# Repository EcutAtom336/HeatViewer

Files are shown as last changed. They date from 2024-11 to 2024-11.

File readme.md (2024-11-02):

# 手持热成像 - HeatViewer

## 项目简介

- 该项目是基于立创·天空星开发板-GD32F407VET6-青春版的手持热成像，使用 MLX90640 红外传感器和 OV7725 可见光图像传感器，支持红外可见光图像融合。

## 快速链接

- [Github](https://github.com/EcutAtom336/Heatviewer)

- [立创开源硬件平台](http://oshwhub.com/dter/heatviewer)

## 功能描述

- 使用 MLX90640 红外传感器，分辨率 32 \* 24，使用软件插值提高分辨率至 64 \* 48。

- 使用 OV7725 图像传感器，支持可见光融合。

- 内置 18650 锂电池，使用 Type-C 接口供充电。

- 可外接 TF 卡，截图保存至 TF 卡。

- 支持可见光照明和激光指示。

- 发射率可调。

- 中心温度和温度极值显示，高温报警。

## 用户交互

- 按键 1：电源键（屏幕面板左上）

  用于开启和关闭热成像仪。

- 按键 2：菜单键（屏幕面板右上）

  用于打开/关闭菜单。

- 按键 3：多功能键 1（屏幕面板中上）

  在菜单界面为上建，在热成像界面为可见光照明开启/关闭键。

- 按键 4：多功能键 2（屏幕面板中下）

  在菜单界面为下键，在热成像界面为激光指示开启/关闭键。

- 按键 5：多功能键 3（扳机键）

  在菜单界面为确认键，在热成像界面为截图键。

## 复刻指南

### 硬件

- 项目 BOM 表在 **/doc/production/bom** 下。

- 3D 打印外壳文件在 **/doc/production/3d_print** 下。

- PCB 制造文件在 **/doc/production/pcb** 下。

- 为减小 pcb 大小，修改天空星开发板的封装排针为贴片形式，可使用贴片排针或贴片排母加直插排针的方式，推荐使用贴片排母加直插排针的方式，以防焊接错误难以修改。

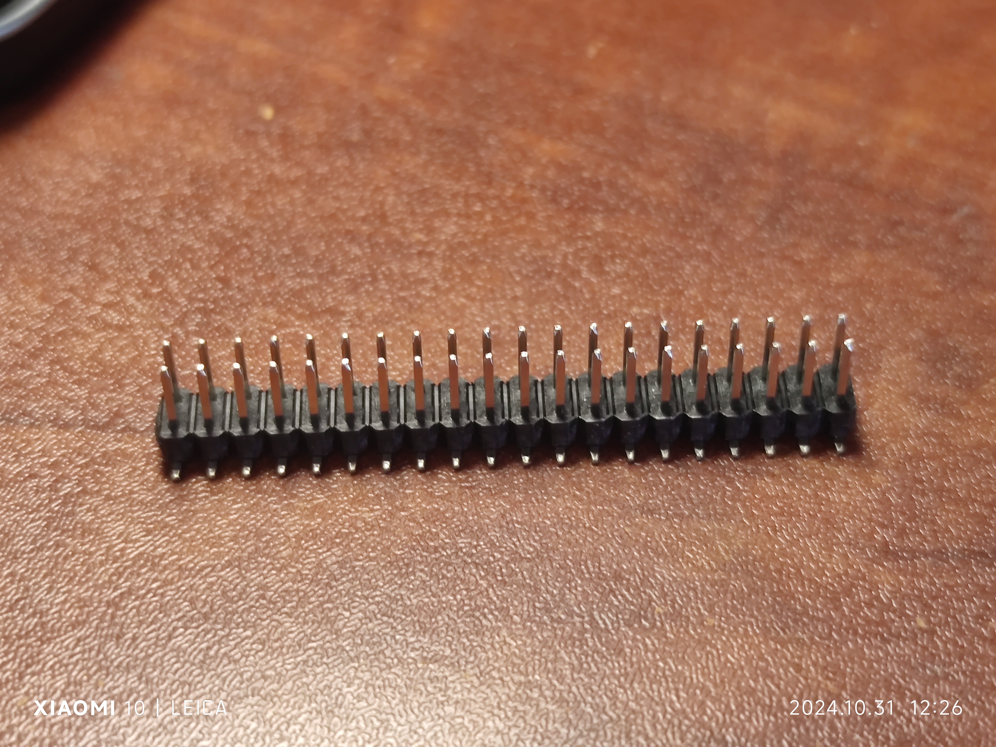
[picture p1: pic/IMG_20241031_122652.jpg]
贴片排针


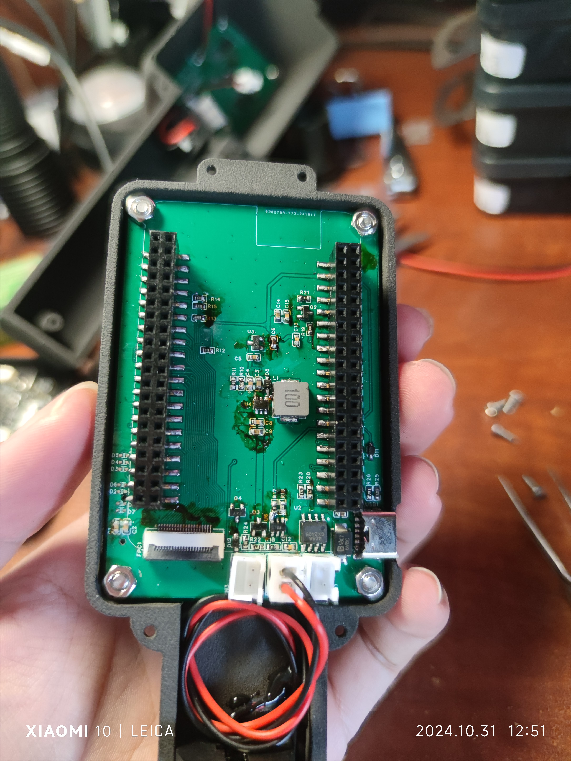
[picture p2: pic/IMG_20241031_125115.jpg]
贴片排母加直插排针


- 传感器 PCB 安装

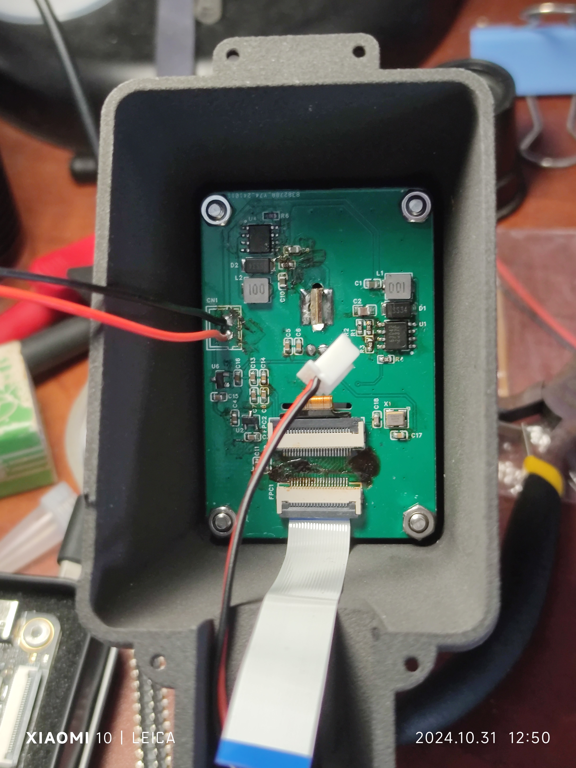
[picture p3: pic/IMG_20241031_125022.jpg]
传感器 PCB 安装


- 主控板 PCB 和电池座安装

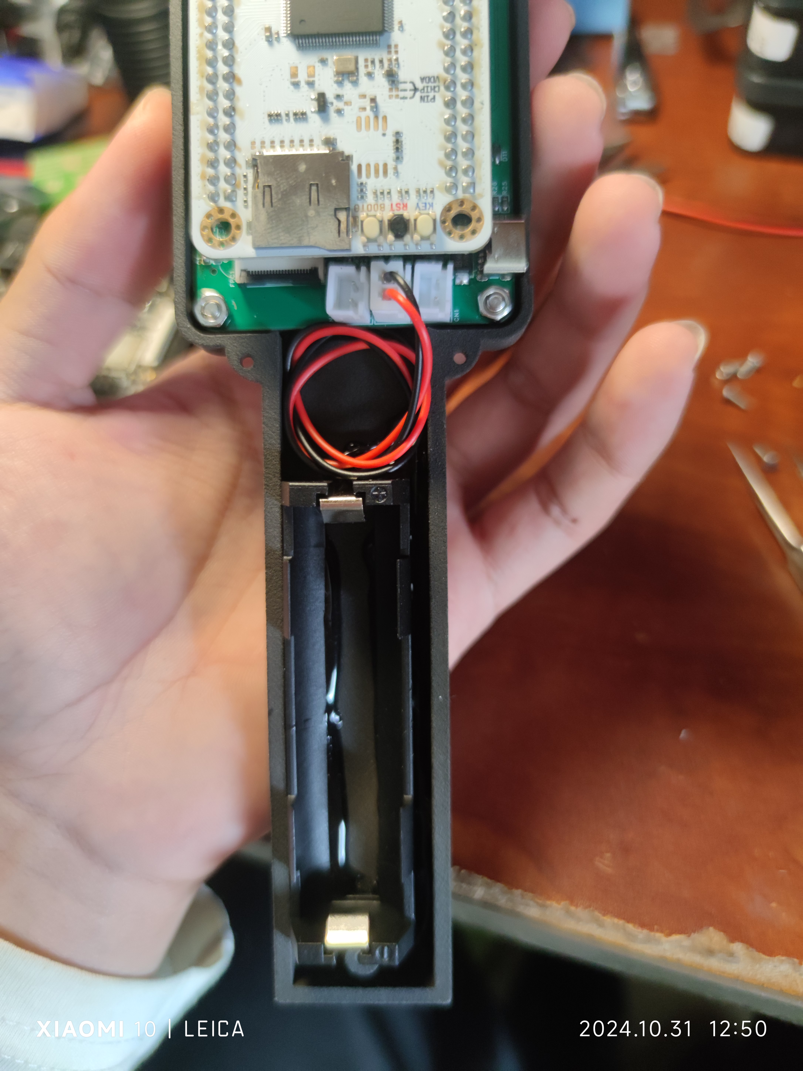
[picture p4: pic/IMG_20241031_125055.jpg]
主控板 PCB 安装


- 激光二极管安装

1. 使用这种激光二极管，将导线和限流电阻拆下。
激光二极管

2. 注意正负极，有两个焊点的是原来有电阻的那面。
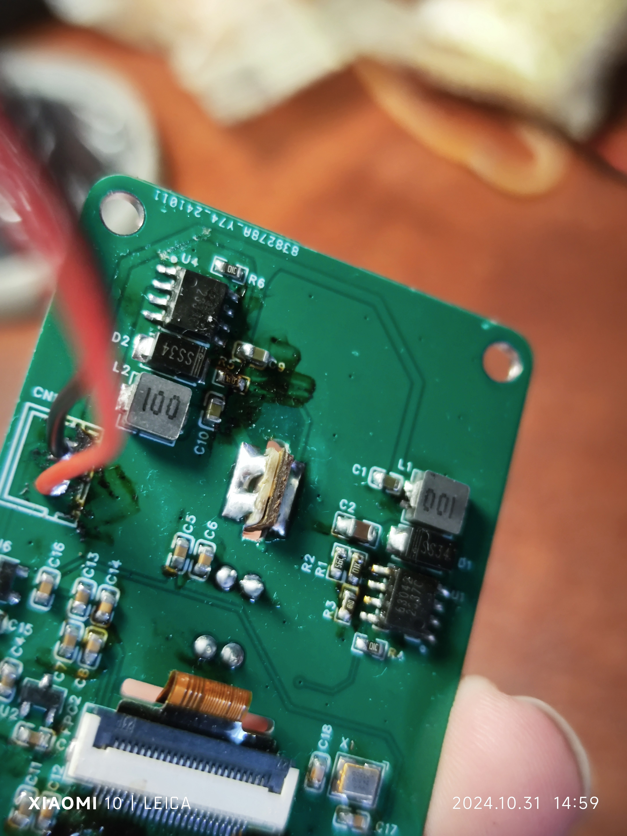
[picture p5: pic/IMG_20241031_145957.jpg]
注意正负极


- 摄像头底部需要使用胶水粘接，可使用硅橡胶。

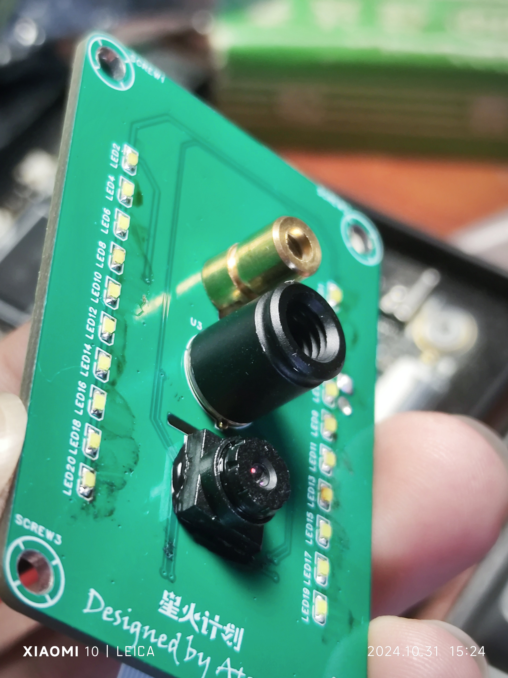
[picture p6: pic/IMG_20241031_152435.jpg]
摄像头细节


### 软件

- 软件使用 EIDE 开发，源码在 /embed 下，该目录 readme 有软件介绍。

### 烧录

- 已编译的固件已上传至附件。

- 有多种方式烧录固件，可前往[立创开发板资料](https://wiki.lckfb.com/zh-hans/tkx/tkx-gd32f407vet6/beginner/download.html)查看详细教程。

## 备注

- 演示视频链接：

1. [【星火计划-悬赏赛道】手持热成像-HeatViewer 功能演示](https://www.bilibili.com/video/BV1wkymYdEMF/?spm_id_from=333.999.0.0)

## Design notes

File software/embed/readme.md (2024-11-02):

# 手持热成像 - HeatViewer 软件部分

## 子模块（位于 hal）

- buzzer

对应用提供预设的 buzzer 音频。

- hw_init

硬件初始化相关。

- laser

激光指示相关。

- led

led 相关。

- power_manage

电源管理相关。

- sd_card_ex

sd 卡拓展模块，用于检测 sd 卡是否存在。

- sd_card

gd32 官方提供的 sd card 驱动库。

- sw_init

软件初始化相关。

## 应用模块（位于 app）

- app

主应用程序。

- mlx90640_handler

mlx90640 数据处理程序。

- on_board_led

开发板 led 闪烁。

## 其他软件

- 响应式按键管理库 [MultiButton](https://github.com/0x1abin/MultiButton)

- 轻量级 log 库 [EasyLogger](https://github.com/armink/EasyLogger.git)

- 轻量级 rtos [Freertos](https://github.com/FreeRTOS/FreeRTOS.git)

- ARM Cortex-M 系列 MCU 错误追踪库 [CmBacktrace](https://github.com/armink/CmBacktrace?tab=readme-ov-file)

- 通用 FAT 文件系统模块 [FatFs](https://github.com/abbrev/fatfs)

- MLX90640 官方驱动库 [MLX90640Driver](https://github.com/melexis/mlx90640-library)

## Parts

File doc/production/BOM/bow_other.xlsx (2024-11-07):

序号 |  | 数量 | 备注
1 | M2 螺母 | 5
2 | M3 螺母 | 9
3 | M2 * 25 扁头螺丝 | 1 | 固定扳机
4 | M2 * 6 扁头螺丝 | 4 | 外壳
5 | M3 * 30 扁头螺丝 | 1 | 外壳
6 | M3 * 10 扁头螺丝 | 8 | 固定 PCB
7 | 2 * 20P 贴片排母 | 2
8 | 2 * 20P 直插排针 | 2
9 | 18650 电池 | 1
10 | 激光 | 1 | 3V可调激光管激光头铜头6MM外径激光二极管红色点状激光模组-淘宝网 (https://item.taobao.com/item.htm?_u=1207b9sukhd830&id=522576364570&spm=a1z09.2.0.0.6a0b2e8durT2D2)
11 | 屏幕 | 1 | 1.8寸液晶屏 1.8寸TFT LCD SPI串口TFT彩屏128x160 st7735-淘宝网 (https://item.taobao.com/item.htm?_u=1207b9sukh603f&id=522810152497&skuId=4663658166508)
12 | 电池盒 | 1 | 立创编号C19184084
13 | pfc排线，0.5mm，20p，15cm，同向 | 1 | FFC/FPC软排线 扁平液晶连接线 0.5/1.0mm间距4P5P6P10P20P40P60P-淘宝网 (https://item.taobao.com/item.htm?_u=2207b9sukh15e7&id=675765050898&skuId=4854765532479)
14 | ov7725，2cm | 1 | OV7725摄像头 7725模组模块 30万像素 适用于STM32 ESP32 K210-淘宝网 (https://item.taobao.com/item.htm?_u=7207b9sukhbafa&id=642622087960&skuId=5227315767937)

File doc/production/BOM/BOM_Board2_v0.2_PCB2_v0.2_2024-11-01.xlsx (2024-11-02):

No. | Quantity | Comment | Designator | Footprint | Value | Manufacturer Part | Manufacturer | Supplier Part | Supplier
1 | 3 | 10uF | C1,C9,C10 | C0603 | 10uF | CL10A106MA8NRNC | SAMSUNG(三星) | C96446 | LCSC
2 | 1 | 10uF | C2 | C0805 | 10uF | GRM21BR61H106KE43L | muRata(村田) | C440198 | LCSC
3 | 8 | 1uF | C3,C4,C5,C7,C11,C13,C15,C16 | C0603 | 1uF | CL10A105KB8NNNC | SAMSUNG(三星) | C15849 | LCSC
4 | 5 | 100nF | C6,C8,C12,C14,C17 | C0603 | 100nF | CC0603KRX7R9BB104 | YAGEO(国巨) | C14663 | LCSC
5 | 1 | 15pF | C18 | C0603 | 15pF | CL10C150JB8NNNC | SAMSUNG(三星) | C1644 | LCSC
6 | 1 | ZX-XH2.54-2PZZ | CN1 | CONN-TH_2P-P2.50_HX25003-2A |  | ZX-XH2.54-2PZZ | Megastar(兆星) | C7429632 | LCSC
7 | 2 | SS34-MS | D1,D2 | DO-214AC_L4.3-W2.7-LS5.0-RD |  | SS34-MS | MSKSEMI(美森科) | C2836396 | LCSC
8 | 1 | FPC-05F-20PH20 | FPC1 | FPC-SMD_20P-P0.50_XUNPU_FPC-05F-20PH20 |  | FPC-05F-20PH20 | XUNPU(讯普) | C2856803 | LCSC
9 | 1 | AFC01-S24FCA-00 | FPC2 | FPC-SMD_P0.50-24P_FGS-XJ-H2.0 |  | AFC01-S24FCA-00 | JS(钜硕电子) | C262669 | LCSC
10 | 2 | 10uH | L1,L2 | IND-SMD_L4.4-W4.2 | 10uH | APH0420T100M | APV(爱普微) | C5349663 | LCSC
11 | 20 | KT-0603W | LED1,LED2,LED3,LED4,LED5,LED6,LED7,LED8,LED9,LED10,LED11,LED12,LED13,LED14,LED15,LED16,LED17,LED18,LED19,LED20 | LED0603-R-RD_WHITE |  | KT-0603W | KENTO | C2290 | LCSC
12 | 2 | 10Ω | R1,R5 | R0603 | 10Ω | 0603WAF100JT5E | UNI-ROYAL(厚声) | C22859 | LCSC
13 | 1 | 37.4kΩ | R2 | R0603 | 37.4kΩ | 0603WAF3742T5E | UNI-ROYAL(厚声) | C23033 | LCSC
14 | 1 | 1kΩ | R3 | R0603 | 1kΩ | 0603WAF1001T5E | UNI-ROYAL(厚声) | C21190 | LCSC
15 | 2 | 10kΩ | R4,R6 | R0603 | 10kΩ | 0603WAF1002T5E | UNI-ROYAL(厚声) | C25804 | LCSC
16 | 2 | LGS63042EP | U1,U4 | ESOP-8_L4.9-W3.9-P1.27-LS6.0-TL-EP3.3 |  | LGS63042EP | Legend-Si(棱晶半导体) | C5280696 | LCSC
17 | 1 | XC6206P182MR | U2 | SOT-23-3_L3.0-W1.7-P0.95-LS2.9-BR |  | XC6206P182MR | UMW(友台半导体) | C347373 | LCSC
18 | 1 | MLX90640ESF-BAB-000-TU | U3 | TO-39-4_MELEXIS_MLX90640 |  | MLX90640ESF-BAB-000-TU | Melexis(比利时迈来芯) | C488251 | LCSC
19 | 1 | XC6206P332MR | U6 | SOT-23-3_L2.9-W1.3-P0.95-LS2.4-BR |  | XC6206P332MR | YONGYUTAI(永裕泰) | C2909968 | LCSC
20 | 1 | 24MHz | X1 | OSC-SMD_4P-L3.2-W2.5-BL | 24MHz | OT2EL4C4JI-111OLP-24M | YXC(扬兴晶振) | C5203548 | LCSC

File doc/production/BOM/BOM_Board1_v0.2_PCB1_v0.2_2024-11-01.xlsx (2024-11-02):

No. | Quantity | Comment | Designator | Footprint | Value | Manufacturer Part | Manufacturer | Supplier Part | Supplier
1 | 1 | 4kHz | BUZZER1 | BUZ-SMD_L5.0-W5.5-P4.60 | 4kHz | MLT-5020 | 华能 | C94598 | LCSC
2 | 1 | 10uF | C1 | C0603 | 10uF | CL10A106MA8NRNC | SAMSUNG(三星) | C96446 | LCSC
3 | 6 | 100nF | C2,C4,C8,C12,C13,C15 | C0603 | 100nF | CC0603KRX7R9BB104 | YAGEO(国巨) | C14663 | LCSC
4 | 2 | 22uF | C3,C9 | C0603 | 22uF | CL10A226MQ8NRNC | SAMSUNG(三星) | C59461 | LCSC
5 | 5 | 1uF | C5,C6,C10,C11,C14 | C0603 | 1uF | CL10A105KB8NNNC | SAMSUNG(三星) | C15849 | LCSC
6 | 1 | 2.2uF | C7 | C0603 | 2.2uF | CL10A225KO8NNNC | SAMSUNG(三星) | C23630 | LCSC
7 | 3 | ZX-XH2.54-2PZZ | CN1,CN2,CN3 | CONN-TH_2P-P2.50_HX25003-2A |  | ZX-XH2.54-2PZZ | Megastar(兆星) | C7429632 | LCSC
8 | 7 | CESDBLC5V0D7 | D1,D2,D3,D4,D5,D6,D7 | SOD-723_L1.0-W0.6-LS1.4-BI |  | CESDBLC5V0D7 | CJ(江苏长电/长晶) | C119072 | LCSC
9 | 4 | 1N5819WS | D8,D9,D11,D12 | SOD-323_L1.8-W1.3-LS2.5-RD |  | 1N5819WS | Hottech(合科泰) | C191023 | LCSC
10 | 1 | P6SMB6.8CA/TR13 | D10 | SMB_L4.6-W3.6-LS5.3-BI |  | P6SMB6.8CA/TR13 | Brightking(君耀电子) | C78395 | LCSC
11 | 1 | FPC-05F-20PH20 | FPC1 | FPC-SMD_20P-P0.50_XUNPU_FPC-05F-20PH20 |  | FPC-05F-20PH20 | XUNPU(讯普) | C2856803 | LCSC
12 | 1 | 10uH | L1 | IND-SMD_L7.3-W6.8 | 10uH | FXL0630-100-M | cjiang(长江微电) | C167223 | LCSC
13 | 1 | KT-0603R | LED1 | LED0603-RD |  | KT-0603R | KENTO | C2286 | LCSC
14 | 1 | LTST-C193TBKT-5A | LED2 | LED0603-RD |  | LTST-C193TBKT-5A | LITEON(光宝) | C125103 | LCSC
15 | 3 | SS8050 | Q1,Q2,Q4 | SOT-23-3_L2.9-W1.3-P1.90-LS2.4-BR |  | SS8050 | CJ(江苏长电/长晶) | C2150 | LCSC
16 | 1 | AO3401-HXY | Q3 | SOT-23-3_L2.9-W1.3-P1.90-LS2.4-BR |  | AO3401-HXY | HXY MOSFET(华轩阳电子) | C4748805 | LCSC
17 | 10 | 10kΩ | R1,R2,R3,R4,R5,R9,R16,R20,R21,R27 | R0603 | 10kΩ | 0603WAF1002T5E | UNI-ROYAL(厚声) | C25804 | LCSC
18 | 5 | 1kΩ | R6,R7,R8,R11,R24 | R0603 | 1kΩ | 0603WAF1001T5E | UNI-ROYAL(厚声) | C21190 | LCSC
19 | 1 | 6.2kΩ | R10 | R0603 | 6.2kΩ | 0603WAF6201T5E | UNI-ROYAL(厚声) | C4260 | LCSC
20 | 4 | 2kΩ | R12,R13,R14,R15 | R0603 | 2kΩ | 0603WAF2001T5E | UNI-ROYAL(厚声) | C22975 | LCSC
21 | 1 | 0Ω | R17 | R0603 | 0Ω | 0603WAF0000T5E | UNI-ROYAL(厚声) | C21189 | LCSC
22 | 1 | 100Ω | R18 | R0603 | 100Ω | 0603WAF1000T5E | UNI-ROYAL(厚声) | C22775 | LCSC
23 | 1 | 10Ω | R19 | R0603 | 10Ω | 0603WAF100JT5E | UNI-ROYAL(厚声) | C22859 | LCSC
24 | 3 | 22kΩ | R22,R23,R28 | R0603 | 22kΩ | 0603WAF2202T5E | UNI-ROYAL(厚声) | C31850 | LCSC
25 | 2 | 5.1kΩ | R25,R26 | R0603 | 5.1kΩ | 0603WAF5101T5E | UNI-ROYAL(厚声) | C23186 | LCSC
26 | 4 | TS-1002S-08026C | SW1,SW2,SW3,SW4 | SW-SMD_4P-L6.0-W6.0-P4.50-LS9.0-2 |  | TS-1002S-08026C | XUNPU(讯普) | C455116 | LCSC
27 | 1 | HX TF-CARD H1.8 SY | U1 | TF-SMD_HX-TF-CARD-H1.8-SY |  | HX TF-CARD H1.8 SY | hanxia(韩下) | C19189038 | LCSC
28 | 1 | GX4056 | U2 | ESOP-8_L4.9-W3.9-P1.27-LS6.0-BL-EP |  | GX4056 | 国芯佳品 | C5259236 | LCSC
29 | 2 | XC6206P332MR | U3,U5 | SOT-23-3_L2.9-W1.3-P0.95-LS2.4-BR |  | XC6206P332MR | YONGYUTAI(永裕泰) | C2909968 | LCSC
30 | 1 | MT3608 | U4 | SOT-23-6_L2.9-W1.6-P0.95-LS2.8-BL |  | MT3608 | 西安航天民芯 | C84817 | LCSC
31 | 1 | DW06 | U6 | SOT-23-6_L2.9-W1.6-P0.95-LS2.8-BL |  | DW06 | JSMSEMI(杰盛微) | C917080 | LCSC
32 | 1 | TYPE-C 6P(040新) | USB1 | USB-C-SMD_TYPE-C-6P |  | TYPE-C 6P(040新) | SHOU HAN(首韩) | C2887422 | LCSC

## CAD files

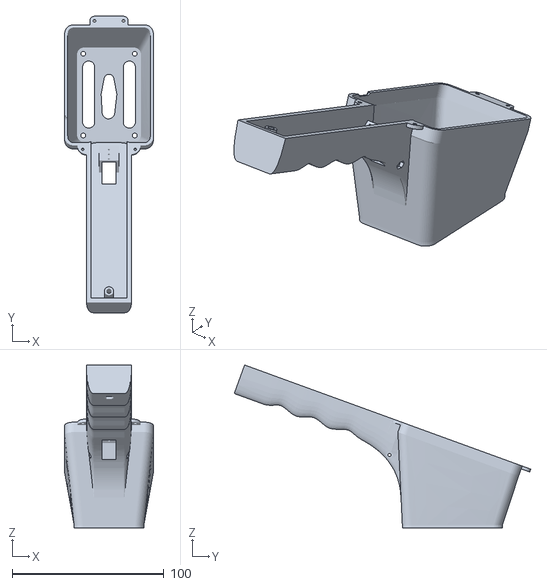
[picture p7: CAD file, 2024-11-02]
doc/production/3d_print/后外壳.STL
58.3 x 195.3 x 107.3

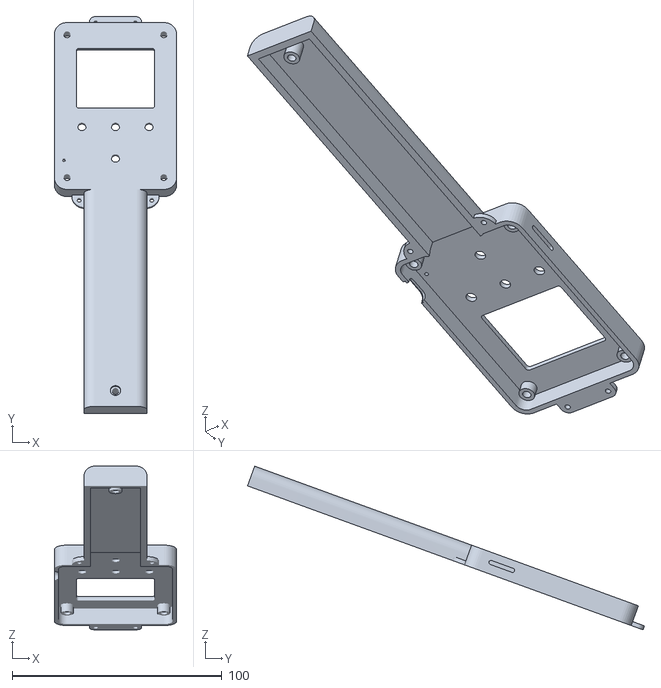
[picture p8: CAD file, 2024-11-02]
doc/production/3d_print/前外壳.STL
58.3 x 189.2 x 78.0

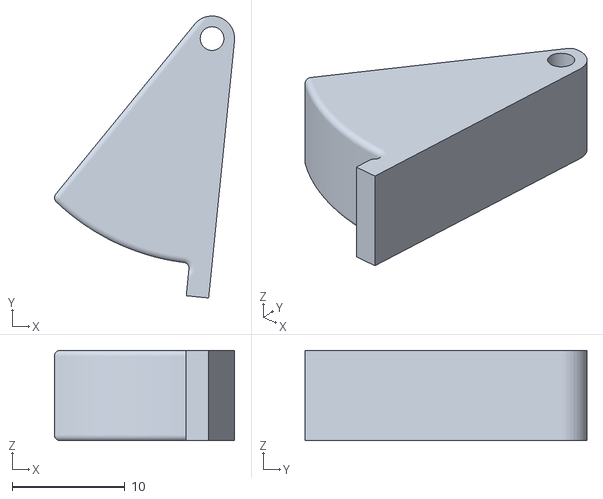
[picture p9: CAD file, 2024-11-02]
doc/production/3d_print/扳机.STL
16.0 x 25.0 x 8.00

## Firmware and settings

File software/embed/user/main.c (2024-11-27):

#include "buzzer.h"
#include "hw_init.h"
#include "my_lcd.h"
#include "sw_init.h"
#include "mlx90640_handler.h"
#include "pic.h"
#include "app.h"
///
#define LOG_TAG "main"
#include "elog.h"
//
#include "FreeRTOS.h"
#include "task.h"
///
#include "cm_backtrace.h"
///
#include "systick.h"
#include "gd32f4xx.h"
///
#include <math.h>
#include <stddef.h>
#include <stdio.h>

static void init_code() {
  // 等待 500ms，即长按上电
  vTaskDelay(pdMS_TO_TICKS(500));

  int32_t ret;

  // elog 初始化
  elog_init();
  elog_set_fmt(ELOG_LVL_ASSERT, ELOG_FMT_ALL);
  elog_set_fmt(ELOG_LVL_ERROR, ELOG_FMT_LVL | ELOG_FMT_TAG | ELOG_FMT_TIME);
  elog_set_fmt(ELOG_LVL_WARN, ELOG_FMT_LVL | ELOG_FMT_TAG | ELOG_FMT_TIME);
  elog_set_fmt(ELOG_LVL_INFO, ELOG_FMT_LVL | ELOG_FMT_TAG | ELOG_FMT_TIME);
  elog_set_fmt(ELOG_LVL_DEBUG, ELOG_FMT_LVL | ELOG_FMT_TAG | ELOG_FMT_TIME);
  elog_set_fmt(ELOG_LVL_VERBOSE, ELOG_FMT_LVL | ELOG_FMT_TAG | ELOG_FMT_TIME);
  elog_start();

  // 硬件初始化
  hw_init();

  // 软件初始化
  sw_init();

  // 开机提示音
  buzzer_sing(BuzzerToneSuccess);

  // 显示 logo
  lcd_show_rgb565_pic(0, 0, LOGO_IMG_HEIGHT, LOGO_IMG_WIDTH,
                      (uint16_t*)LOGO_IMG);
  // 请求刷新 LCD
  lcd_refreash_request();

  vTaskDelay(pdMS_TO_TICKS(1500));

  // 应用程序初始化
  app_init();
  mlx90640_handler_init();

  // 删除任务
  vTaskDelete(NULL);
}

int main() {
  // 初始化 USART0
  // 使能时钟
  rcu_periph_clock_enable(RCU_GPIOA);
  rcu_periph_clock_enable(RCU_USART0);
  // IO 配置
  gpio_mode_set(GPIOA, GPIO_MODE_AF, GPIO_PUPD_NONE, GPIO_PIN_9 | GPIO_PIN_10);
  gpio_output_options_set(GPIOA, GPIO_OTYPE_PP, GPIO_OSPEED_2MHZ,
                          GPIO_PIN_9 | GPIO_PIN_10);
  gpio_af_set(GPIOA, GPIO_AF_7, GPIO_PIN_9 | GPIO_PIN_10);
  // 配置 USART0
  usart_baudrate_set(USART0, 115200);
  usart_stop_bit_set(USART0, USART_STB_1BIT);
  usart_parity_config(USART0, USART_PM_NONE);
  usart_word_length_set(USART0, USART_WL_8BIT);
  usart_transmit_config(USART0, USART_TRANSMIT_ENABLE);
  usart_enable(USART0);

  // cm backtrace 初始化
  cm_backtrace_init("HeatViewer", "v1.0.0", "v1.0.0");

  BaseType_t freertos_ret;

  nvic_priority_group_set(NVIC_PRIGROUP_PRE4_SUB0);

  freertos_ret = xTaskCreate(init_code, "init", 1024 * 4 / 4, NULL,
                             configMAX_PRIORITIES - 1, NULL);
  configASSERT(freertos_ret);

  systick_config();

  vTaskStartScheduler();
}

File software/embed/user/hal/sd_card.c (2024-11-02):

/*!
    \file    sdcard.c
    \brief   SD card driver

    \version 2024-01-15, V3.2.0, firmware for GD32F4xx
*/

/*
    Copyright (c) 2024, GigaDevice Semiconductor Inc.

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
    1. Redistributions of source code must retain the above copyright notice,
this list of conditions and the following disclaimer.
    2. Redistributions in binary form must reproduce the above copyright notice,
       this list of conditions and the following disclaimer in the documentation
       and/or other materials provided with the distribution.
    3. Neither the name of the copyright holder nor the names of its
contributors may be used to endorse or promote products derived from this
software without specific prior written permission.

    THIS SOFTWARE IS PROVIDED BY THE COPYRIGHT HOLDERS AND CONTRIBUTORS "AS IS"
AND ANY EXPRESS OR IMPLIED WARRANTIES, INCLUDING, BUT NOT LIMITED TO, THE
IMPLIED WARRANTIES OF MERCHANTABILITY AND FITNESS FOR A PARTICULAR PURPOSE ARE
DISCLAIMED. IN NO EVENT SHALL THE COPYRIGHT HOLDER OR CONTRIBUTORS BE LIABLE FOR
ANY DIRECT, INDIRECT, INCIDENTAL, SPECIAL, EXEMPLARY, OR CONSEQUENTIAL DAMAGES
(INCLUDING, BUT NOT LIMITED TO, PROCUREMENT OF SUBSTITUTE GOODS OR SERVICES;
LOSS OF USE, DATA, OR PROFITS; OR BUSINESS INTERRUPTION) HOWEVER CAUSED AND ON
ANY THEORY OF LIABILITY, WHETHER IN CONTRACT, STRICT LIABILITY, OR TORT
(INCLUDING NEGLIGENCE OR OTHERWISE) ARISING IN ANY WAY OUT OF THE USE OF THIS
SOFTWARE, EVEN IF ADVISED OF THE POSSIBILITY OF SUCH DAMAGE.
*/

#include "sd_card.h"
#include "gd32f4xx_sdio.h"
#include "gd32f4xx_dma.h"
#include <stddef.h>

/* card status of R1 definitions */
#define SD_R1_OUT_OF_RANGE \
  BIT(31) /* command's argument was out of the allowed range */
#define SD_R1_ADDRESS_ERROR \
  BIT(30) /* misaligned address which did not match the block length */
#define SD_R1_BLOCK_LEN_ERROR \
  BIT(29) /* transferred block length is not allowed */
#define SD_R1_ERASE_SEQ_ERROR \
  BIT(28) /* an error in the sequence of erase commands occurred */
#define SD_R1_ERASE_PARAM \
  BIT(27) /* an invalid selection of write-blocks for erase occurred */
#define SD_R1_WP_VIOLATION                                             \
  BIT(26) /* the host attempts to write to a protected block or to the \
             temporary or permanent write protected card */
#define SD_R1_CARD_IS_LOCKED BIT(25) /* the card is locked by the host */
#define SD_R1_LOCK_UNLOCK_FAILED                                           \
  BIT(24) /* a sequence or password error has been detected in lock/unlock \
             card command */
#define SD_R1_COM_CRC_ERROR \
  BIT(23) /* CRC check of the previous command failed */
#define SD_R1_ILLEGAL_COMMAND BIT(22) /* command not legal for the card state \
                                       */
#define SD_R1_CARD_ECC_FAILED \
  BIT(21) /* card internal ECC was applied but failed to correct the data */
#define SD_R1_CC_ERROR BIT(20) /* internal card controller error */
#define SD_R1_GENERAL_UNKNOWN_ERROR \
  BIT(19) /* a general or an unknown error occurred during the operation */
#define SD_R1_CSD_OVERWRITE                                                    \
  BIT(16) /* read only section of the CSD does not match or attempt to reverse \
             the copy or permanent WP bits */
#define SD_R1_WP_ERASE_SKIP BIT(15) /* partial address space was erased */
#define SD_R1_CARD_ECC_DISABLED \
  BIT(14) /* command has been executed without using the internal ECC */
#define SD_R1_ERASE_RESET \
  BIT(13) /* an erase sequence was cleared before executing */
#define SD_R1_READY_FOR_DATA \
  BIT(8) /* correspond to buffer empty signaling on the bus */
#define SD_R1_APP_CMD BIT(5) /* card will expect ACMD */
#define SD_R1_AKE_SEQ_ERROR \
  BIT(3) /* error in the sequence of the authentication process */
#define SD_R1_ERROR_BITS (uint32_t)0xFDF9E008 /* all the R1 error bits */

/* card status of R6 definitions */
#define SD_R6_COM_CRC_ERROR \
  BIT(15) /* CRC check of the previous command failed */
#define SD_R6_ILLEGAL_COMMAND BIT(14) /* command not legal for the card state \
                                       */
#define SD_R6_GENERAL_UNKNOWN_ERROR \
  BIT(13) /* a general or an unknown error occurred during the operation */

/* card state */
#define SD_CARDSTATE_IDLE  ((uint8_t)0x00) /* card is in idle state */
#define SD_CARDSTATE_READY ((uint8_t)0x01) /* card is in ready state */
#define SD_CARDSTATE_IDENTIFICAT \
  ((uint8_t)0x02) /* card is in identificat state */
#define SD_CARDSTATE_STANDBY   ((uint8_t)0x03) /* card is in standby state */
#define SD_CARDSTATE_TRANSFER  ((uint8_t)0x04) /* card is in transfer state */
#define SD_CARDSTATE_DATA      ((uint8_t)0x05) /* card is in data sending state */
#define SD_CARDSTATE_RECEIVING ((uint8_t)0x06) /* card is in receiving state \
                                                */
#define SD_CARDSTATE_PROGRAMMING \
  ((uint8_t)0x07) /* card is in programming state */
#define SD_CARDSTATE_DISCONNECT \
  ((uint8_t)0x08) /* card is in disconnect state */
#define SD_CARDSTATE_LOCKED ((uint32_t)0x02000000) /* card is in locked state \
                                                    */

#define SD_CHECK_PATTERN ((uint32_t)0x000001AA) /* check pattern for CMD8 */
#define SD_VOLTAGE_WINDOW \
  ((uint32_t)0x80100000) /* host 3.3V request in ACMD41 */

/* parameters for ACMD41(voltage validation) */
#define SD_HIGH_CAPACITY \
  ((uint32_t)0x40000000) /* high capacity SD memory card */
#define SD_STD_CAPACITY \
  ((uint32_t)0x00000000) /* standard capacity SD memory card */

/* SD bus width, check SCR register */
#define SD_BUS_WIDTH_4BIT ((uint32_t)0x00040000) /* 4-bit width bus mode */
#define SD_BUS_WIDTH_1BIT ((uint32_t)0x00010000) /* 1-bit width bus mode */

/* masks for SCR register */
#define SD_MASK_0_7BITS   ((uint32_t)0x000000FF) /* mask [7:0] bits */
#define SD_MASK_8_15BITS  ((uint32_t)0x0000FF00) /* mask [15:8] bits */
#define SD_MASK_16_23BITS ((uint32_t)0x00FF0000) /* mask [23:16] bits */
#define SD_MASK_24_31BITS ((uint32_t)0xFF000000) /* mask [31:24] bits */

#define SDIO_FIFO_ADDR    ((uint32_t)0x40012C80) /* address of SDIO_FIFO */
#define SD_FIFOHALF_WORDS \
  ((uint32_t)0x00000008) /* words of FIFO half full/empty */
#define SD_FIFOHALF_BYTES \
  ((uint32_t)0x00000020) /* bytes of FIFO half full/empty */

#define SD_DATATIMEOUT ((uint32_t)0xFFFFFFFF) /* DSM data timeout */
#define SD_MAX_VOLT_VALIDATION \
  ((uint32_t)0x0000FFFF) /* the maximum times of voltage validation */
#define SD_MAX_DATA_LENGTH \
  ((uint32_t)0x01FFFFFF)                    /* the maximum length of data */
#define SD_ALLZERO   ((uint32_t)0x00000000) /* all zero */
#define SD_RCA_SHIFT ((uint8_t)0x10)        /* RCA shift bits */
#define SD_CLK_DIV_INIT \
  ((uint16_t)0x0076) /* SD clock division in initialization phase */
#define SD_CLK_DIV_TRANS \
  ((uint16_t)0x0002) /* SD clock division in transmission phase */

#define SDIO_MASK_INTC_FLAGS \
  ((uint32_t)0x00C007FF) /* mask flags of SDIO_INTC */
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

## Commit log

2024-11-02 第一次提交
    [BOM_Board1_v0.2_PCB1_v0.2_2024-11-01.xlsx, BOM_Board2_v0.2_PCB2_v0.2_2024-11-01.xlsx, bow_other.xlsx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]
2024-11-02 更新 othor_bom.xlsx
    [bow_other.xlsx]
2024-11-07 修改 bom_other.xlsx
    [bow_other.xlsx]
2024-11-27 增加一些注释
